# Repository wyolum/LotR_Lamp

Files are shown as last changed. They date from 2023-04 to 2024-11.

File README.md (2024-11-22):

# LotR_Lamp
3D printed Lord of the Rings inspired table / desk lamp.
Derived from jerome95's LotR Lamp on Instructables at https://www.instructables.com/Lord-of-the-Rings-Lamp/

I've completely redesigned this from the ground up in FreeCAD

## 3D Printed Parts
- BASE : Lamp base, which houses the micro-controller and a barrel socket adapter. Single color in black. Supports are optional (depending on how good the printer is). There are 4 holes for M3 screws. The 4 screws can act as feet, and if wired to the micro-controller, can be used as 4 touch pads to act as buttons. The buttons can then be used to cycle through different animations, or adjust LED intensity etc.
- BASE COVER : 2 color printing. The cover is black, and the embossed text and tree are white
- PILLAR LEFT and RIGHT : Vertical support pillars in two parts for easier printing and assembly. There is a channel for the wires from micro-controller to LED ring. There are a pair of 1.9 mm holes through which you can insert 1.75 mm filament to staple the top part of the two halves of the vertical pillars. The bottom of the pillars have screw fixing holes. Insert pillars through the Base Cover, and then insert the pillars in the Base. Finally, use 4 wood screws / self tapping screws to nicely hold it all together.
- RING COVER : This is the bottom part of the main ring, and is printed in GOLD / COPPER or similar filament.
- RING : This requires 2 color printing. The inner part of the shell and the text is in white / translucent, and the outer shell is in GOLD / COPPER.

## ELECTRONICS
- LED ring, with 64 addressable LEDs, WS2812 or similar.
- Micro-controller : I used Arduino Nano, but any controller will do the job.
- Example code is in the CODE sub folder

## RENDERS

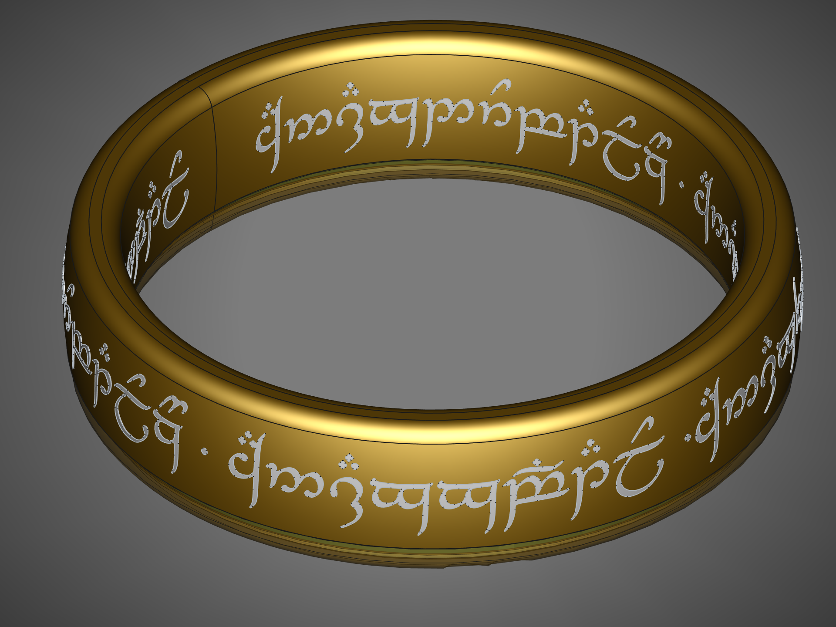
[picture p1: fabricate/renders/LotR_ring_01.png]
LotR Lamp


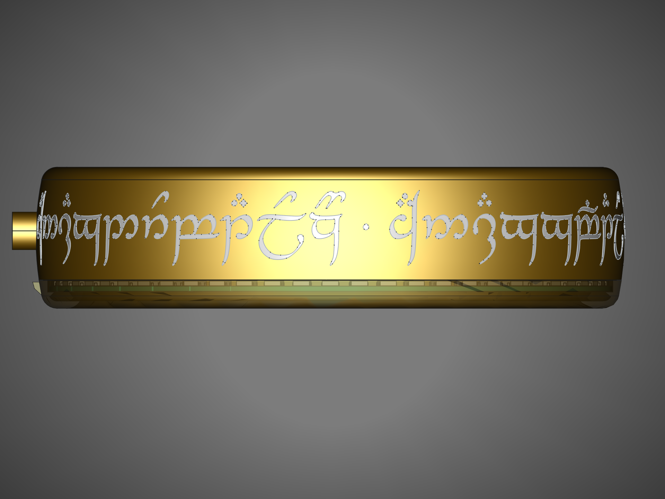
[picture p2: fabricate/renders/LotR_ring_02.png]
LotR Lamp


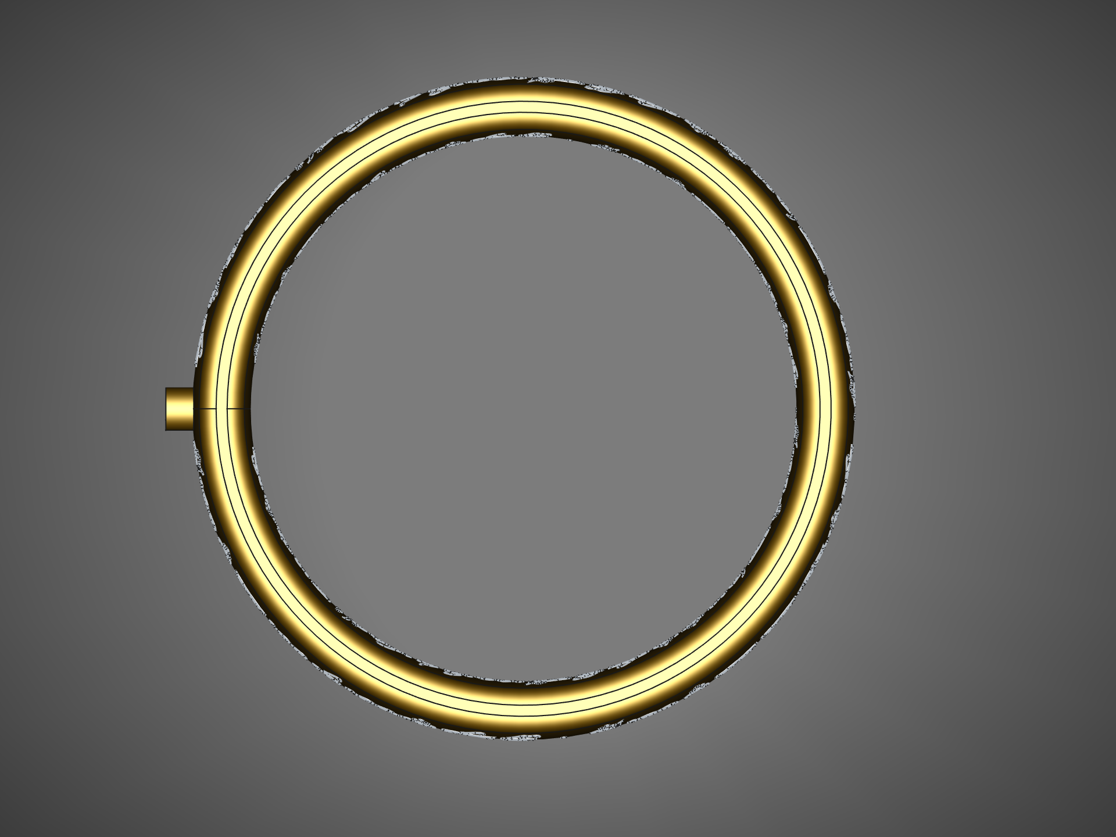
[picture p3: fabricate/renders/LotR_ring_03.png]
LotR Lamp


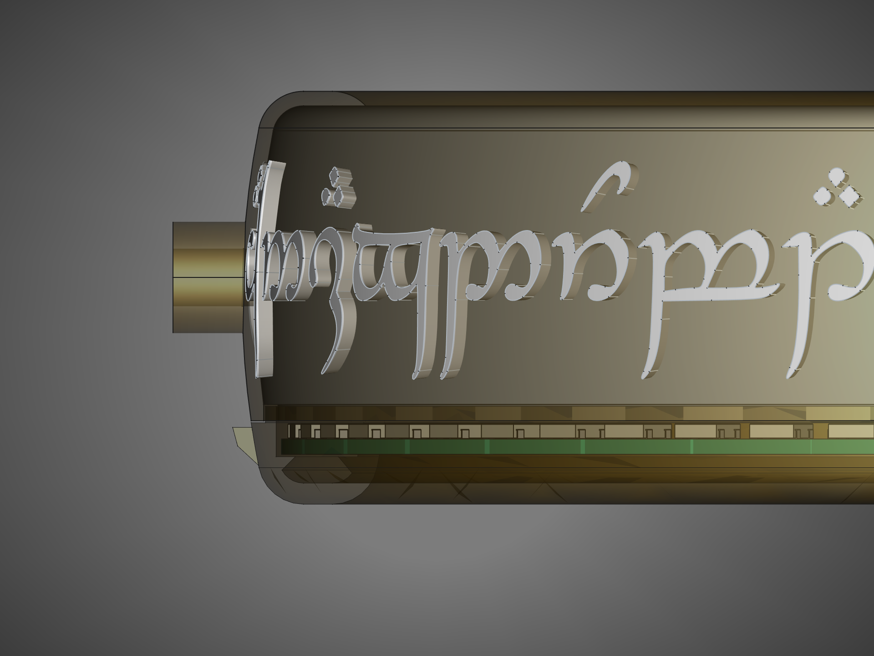
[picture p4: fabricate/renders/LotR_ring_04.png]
LotR Lamp


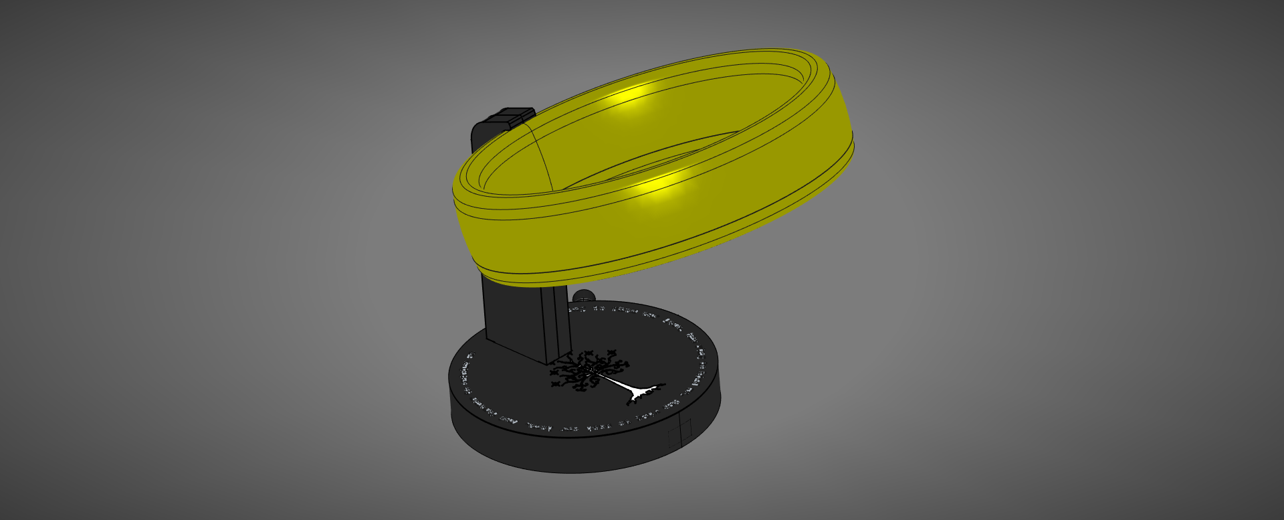
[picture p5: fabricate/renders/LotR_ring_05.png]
LotR Lamp


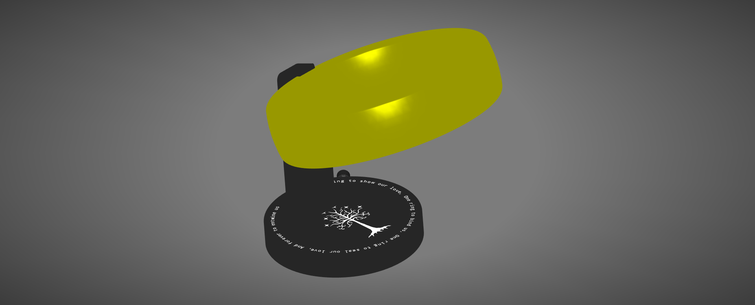
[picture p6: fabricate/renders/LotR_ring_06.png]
LotR Lamp


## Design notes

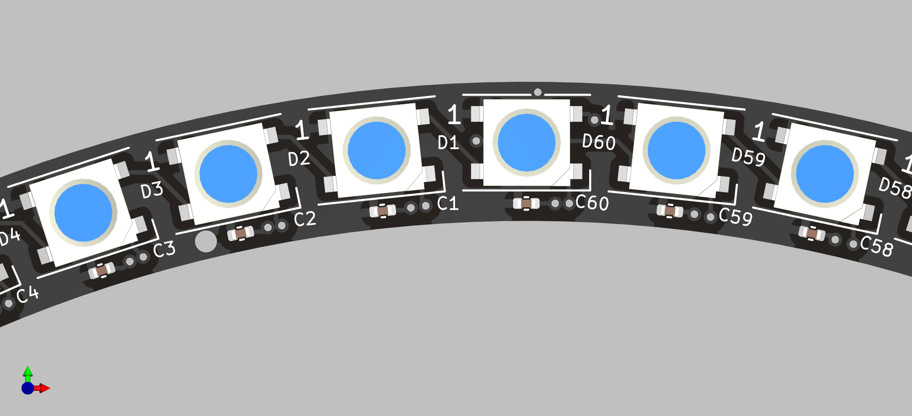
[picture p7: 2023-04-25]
LOTR_LED_RING_KiCAD/renders/LOTR_LED_RING_03.png

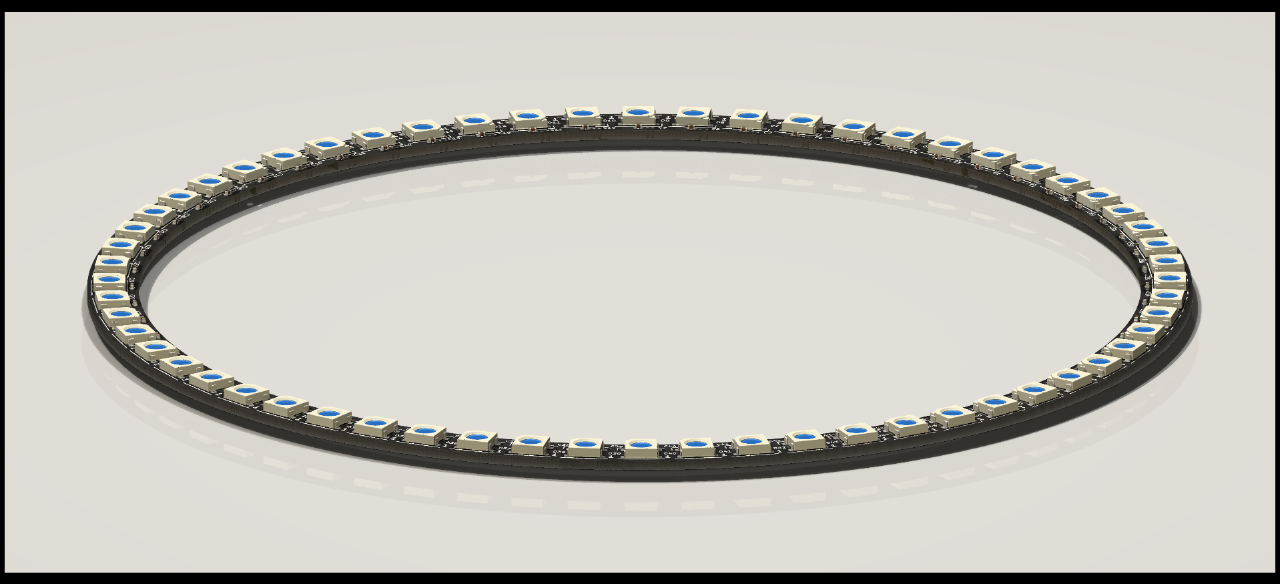
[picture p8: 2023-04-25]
LOTR_LED_RING_KiCAD/renders/LOTR_LED_RING_02.png

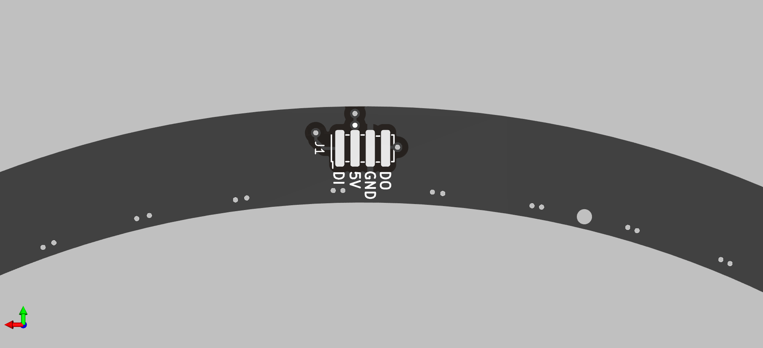
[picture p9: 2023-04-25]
LOTR_LED_RING_KiCAD/renders/LOTR_LED_RING_04.png

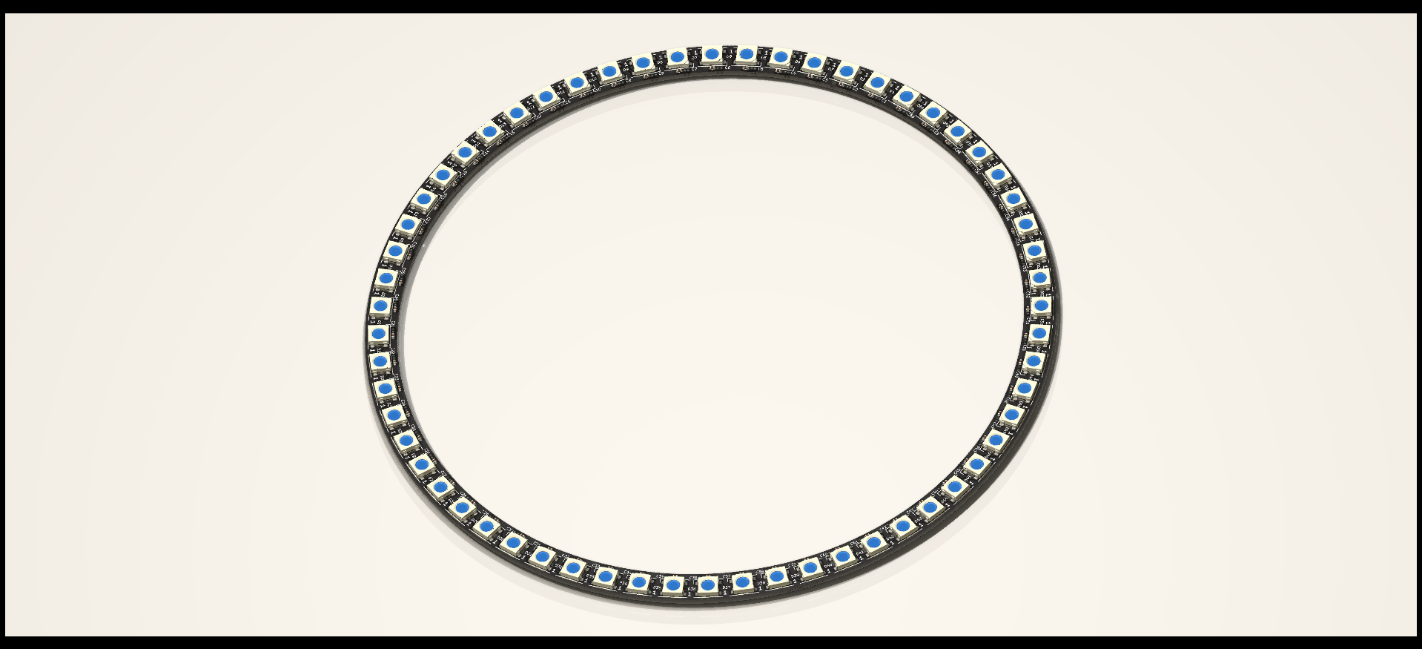
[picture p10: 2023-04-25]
LOTR_LED_RING_KiCAD/renders/LOTR_LED_RING_01.png

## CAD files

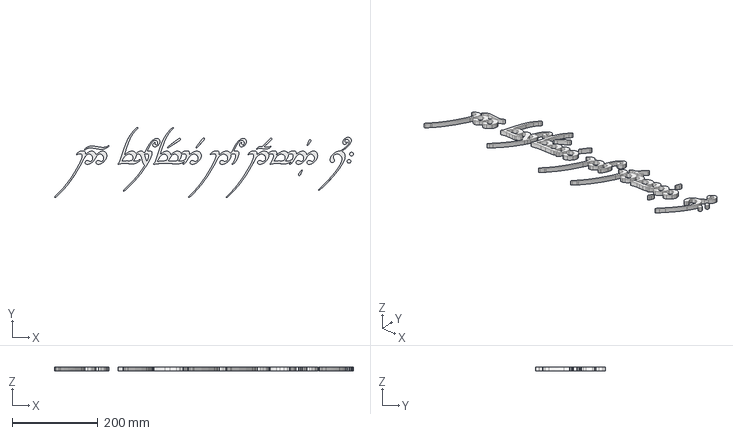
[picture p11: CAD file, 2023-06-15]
fabricate/data/H_N_elvish_line_4.FCStd
699.3 x 164.7 x 10.0 mm

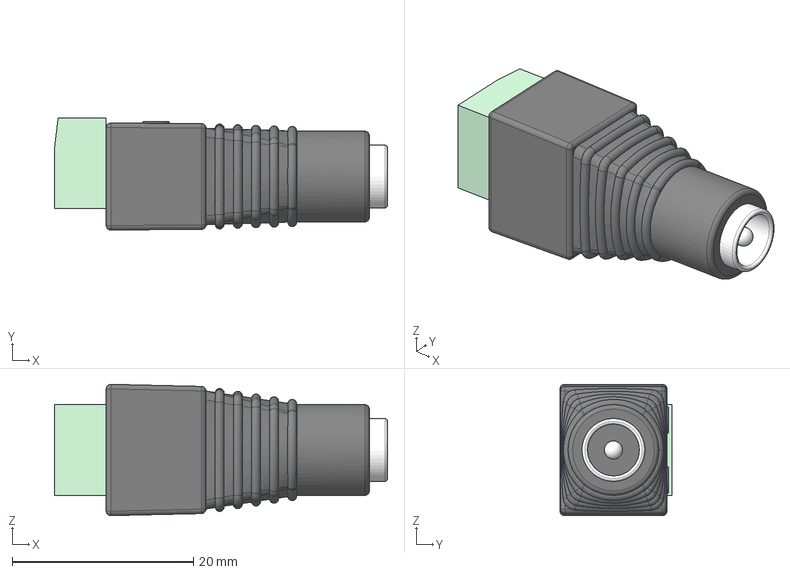
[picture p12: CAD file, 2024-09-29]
fabricate/dc-barrel-jack-adapter-female.step
36.7 x 12.3 x 14.5 mm
Adapter Housing
Housing
Terminal x 2
92000A013 x 2
Ground Jack
Power Jack

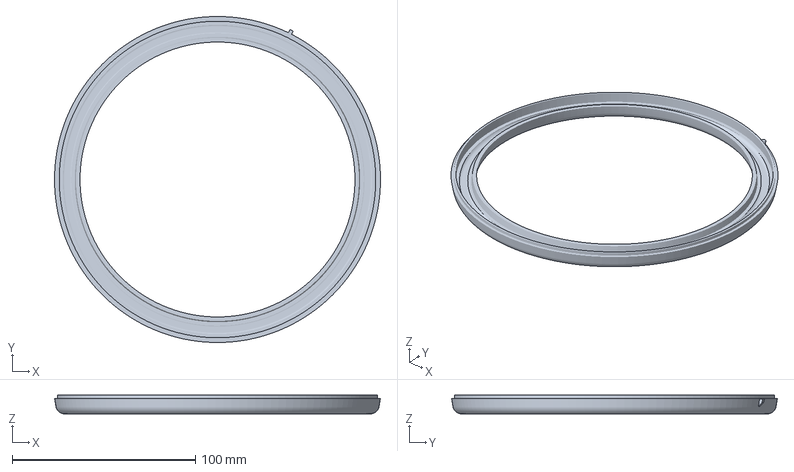
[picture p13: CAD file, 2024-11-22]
fabricate/gcode/LotR_ring_v5-ring_cover.3mf
177.7 x 177.7 x 10.2 mm

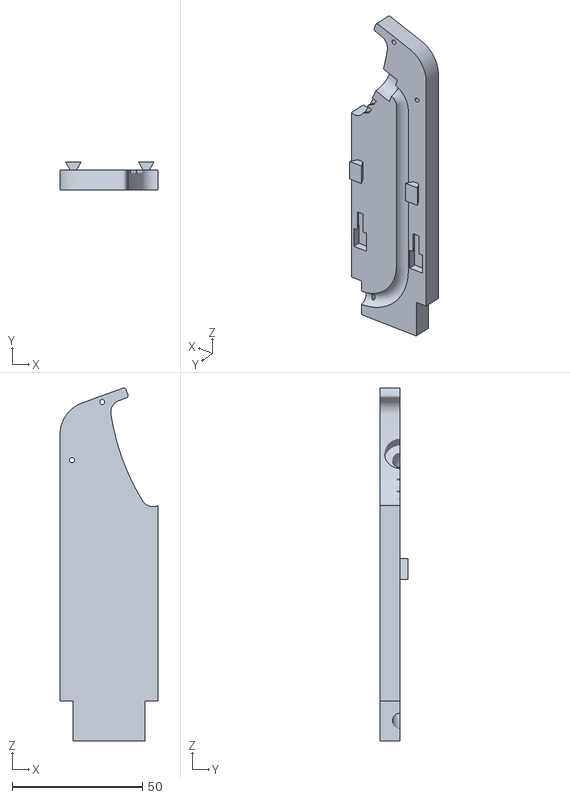
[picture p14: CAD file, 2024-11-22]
fabricate/STL/LotR_Base4-Pillar_Left.stl
37.6 x 10.8 x 135.6

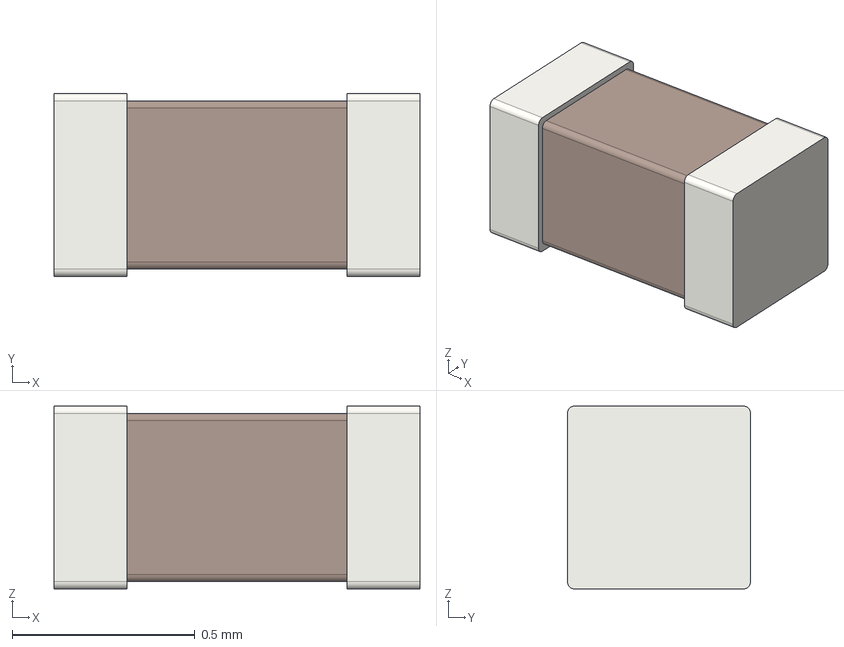
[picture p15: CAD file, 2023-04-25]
LOTR_LED_RING_KiCAD/3D_models/C_0402_1005Metric.step
1.00 x 0.5 x 0.5 mm

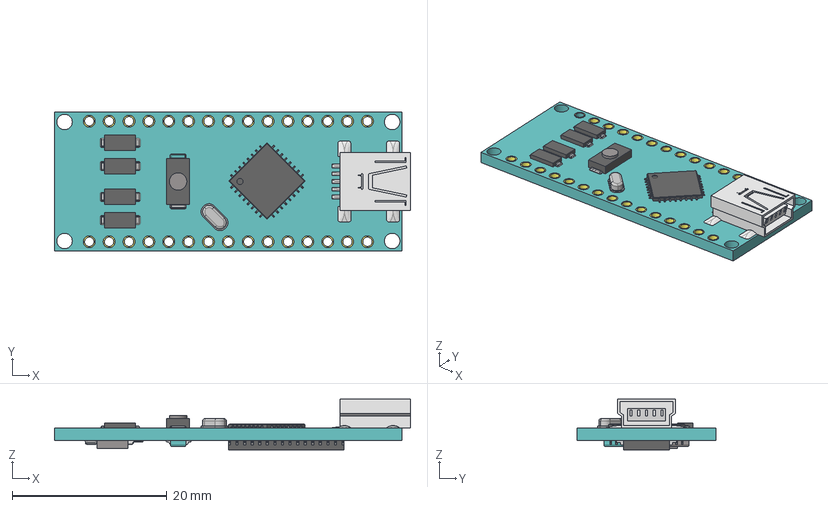
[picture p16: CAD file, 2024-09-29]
fabricate/arduino_nano.step
46.1 x 18.0 x 6.55 mm
USB
Component3(Mirror) x 16
Component5(Mirror) x 4
Component5(Mirror) (1) x 4

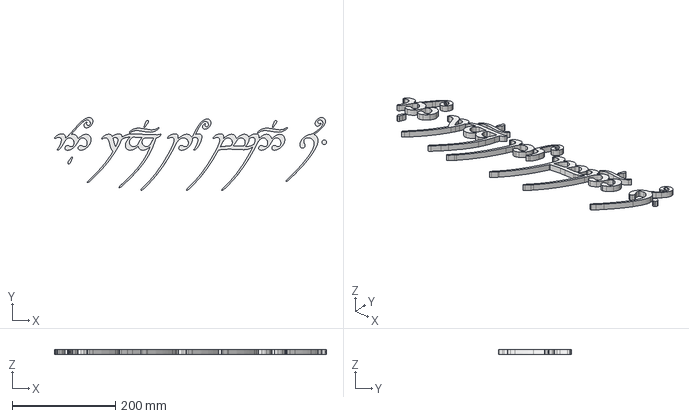
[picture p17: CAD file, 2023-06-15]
fabricate/data/H_N_elvish_line_2.FCStd
527.7 x 141.5 x 10.0 mm

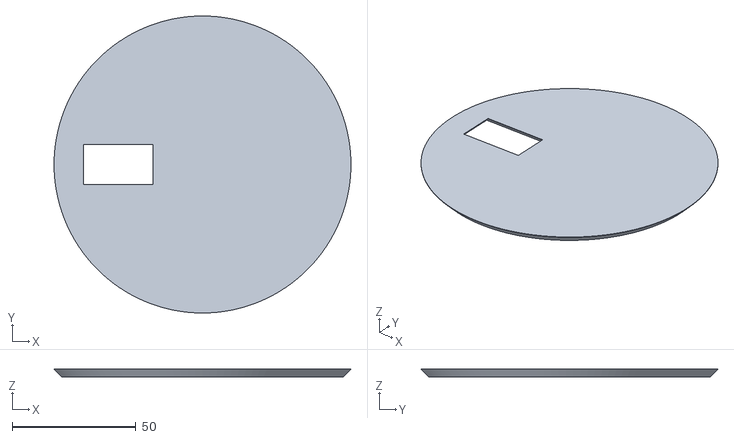
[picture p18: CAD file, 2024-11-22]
fabricate/STL/LotR_Base4-Base_Cover.stl
120.0 x 120.0 x 3.40

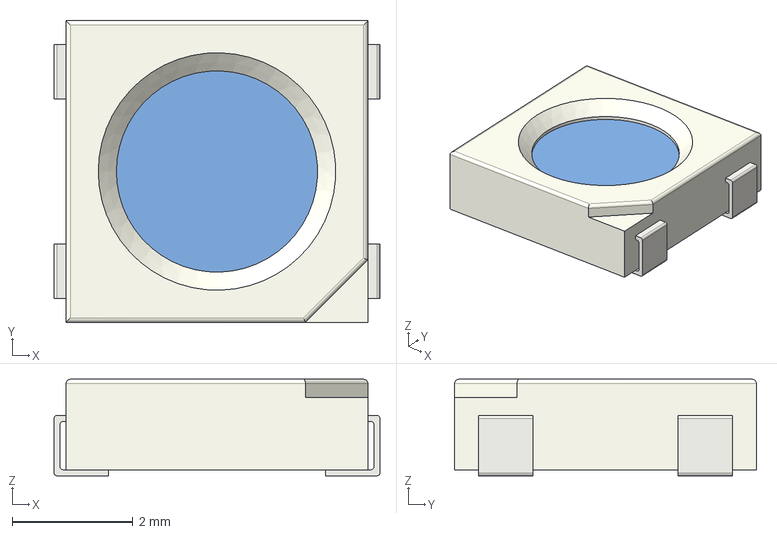
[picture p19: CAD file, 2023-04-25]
LOTR_LED_RING_KiCAD/3D_models/LED_WS2812B_PLCC4_5.0x5.0mm_P3.2mm.step
5.40 x 5.00 x 1.60 mm

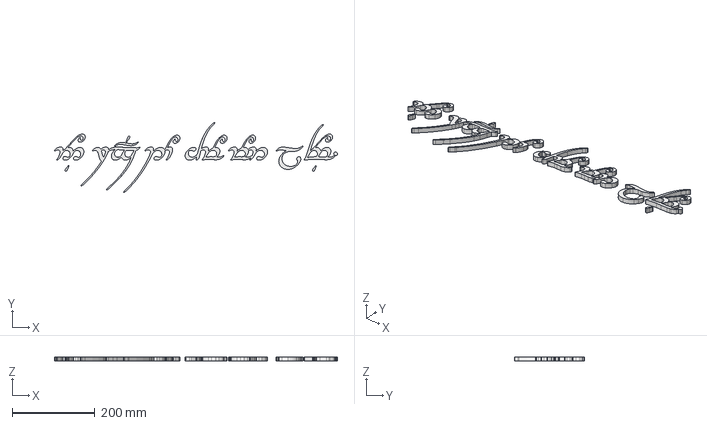
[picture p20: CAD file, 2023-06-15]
fabricate/data/H_N_elvish_line_1.FCStd
685.1 x 169.1 x 10.0 mm

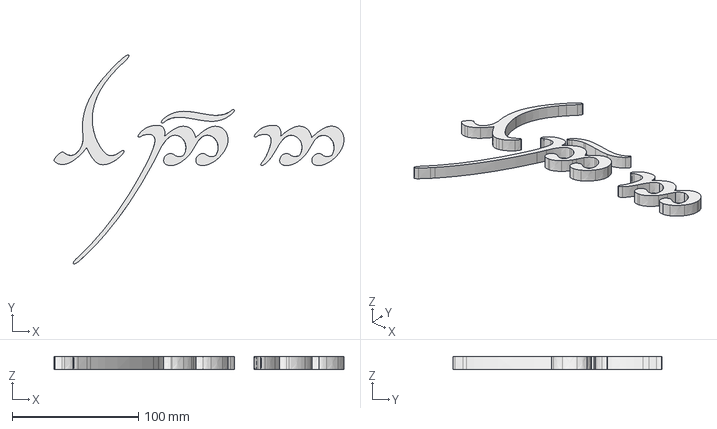
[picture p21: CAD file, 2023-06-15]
fabricate/data/H_N_elvish_line_5.FCStd
229.6 x 165.5 x 10.0 mm

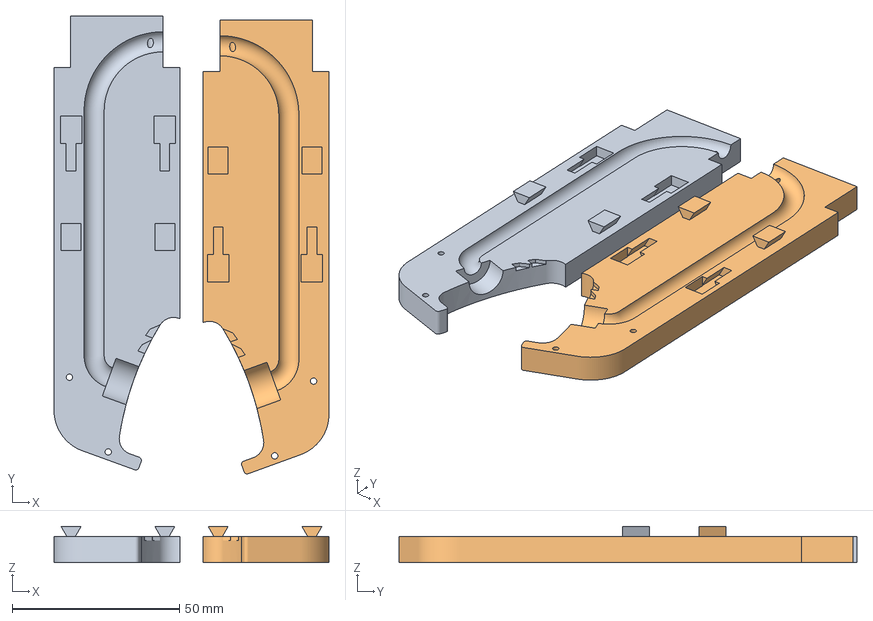
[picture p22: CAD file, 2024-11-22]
fabricate/gcode/LotR_Base4-Pillar_LR.3mf
82.1 x 136.7 x 10.8 mm
LotR_Base4-Pillar_Left.stl
LotR_Base4-Pillar_Right.stl

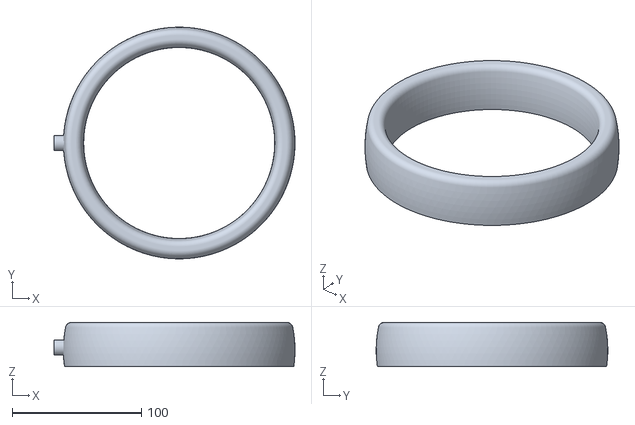
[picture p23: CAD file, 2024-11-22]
fabricate/STL/LotR_ring_v5-Body_outer_gold.stl
186.7 x 179.5 x 34.3

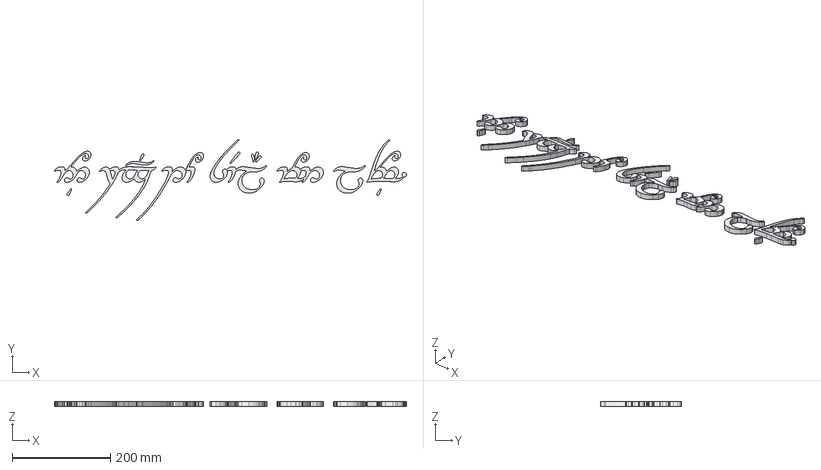
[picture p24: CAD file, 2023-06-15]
fabricate/data/H_N_elvish_line_3.FCStd
716.9 x 165.5 x 10.0 mm

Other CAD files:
fabricate/gcode/LotR_Base4-Pillar_LR.gcode.3mf
fabricate/gcode/LotR_Base4-Base.gcode.3mf
fabricate/STL/LotR_ring_v5-ring_cover.stl
fabricate/gcode/LotR_Base4-Base.3mf
fabricate/STL/LotR_Base4-Base.stl
fabricate/STL/LotR_Base4-Pillar_Right.stl
fabricate/STL/archive/LED_ring_v3_cover.stl
fabricate/STL/archive/LED_ring_v3_gold.stl
fabricate/STL/archive/LotR_Base2-Base.stl
fabricate/STL/archive/LotR_Base2-Body (mirrored).stl
fabricate/STL/archive/LotR_Base2-Body.stl
fabricate/STL/archive/LotR_Base2-Cut001.stl
fabricate/STL/archive/LotR_Base2_bottom.stl
fabricate/STL/archive/LotR_Base2_cover-Top_Cover.stl
fabricate/archive/Barad_dur_base.STL
fabricate/archive/Cover_base.STL
fabricate/archive/LED_ring_amzn_2.FCStd
fabricate/archive/LED_ring_amzn_3.FCStd
fabricate/archive/LED_ring_amzn_6.FCStd
fabricate/archive/LED_ring_amzn_7-ring_cover.step
fabricate/archive/LED_ring_amzn_7-ring_cover.stl
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

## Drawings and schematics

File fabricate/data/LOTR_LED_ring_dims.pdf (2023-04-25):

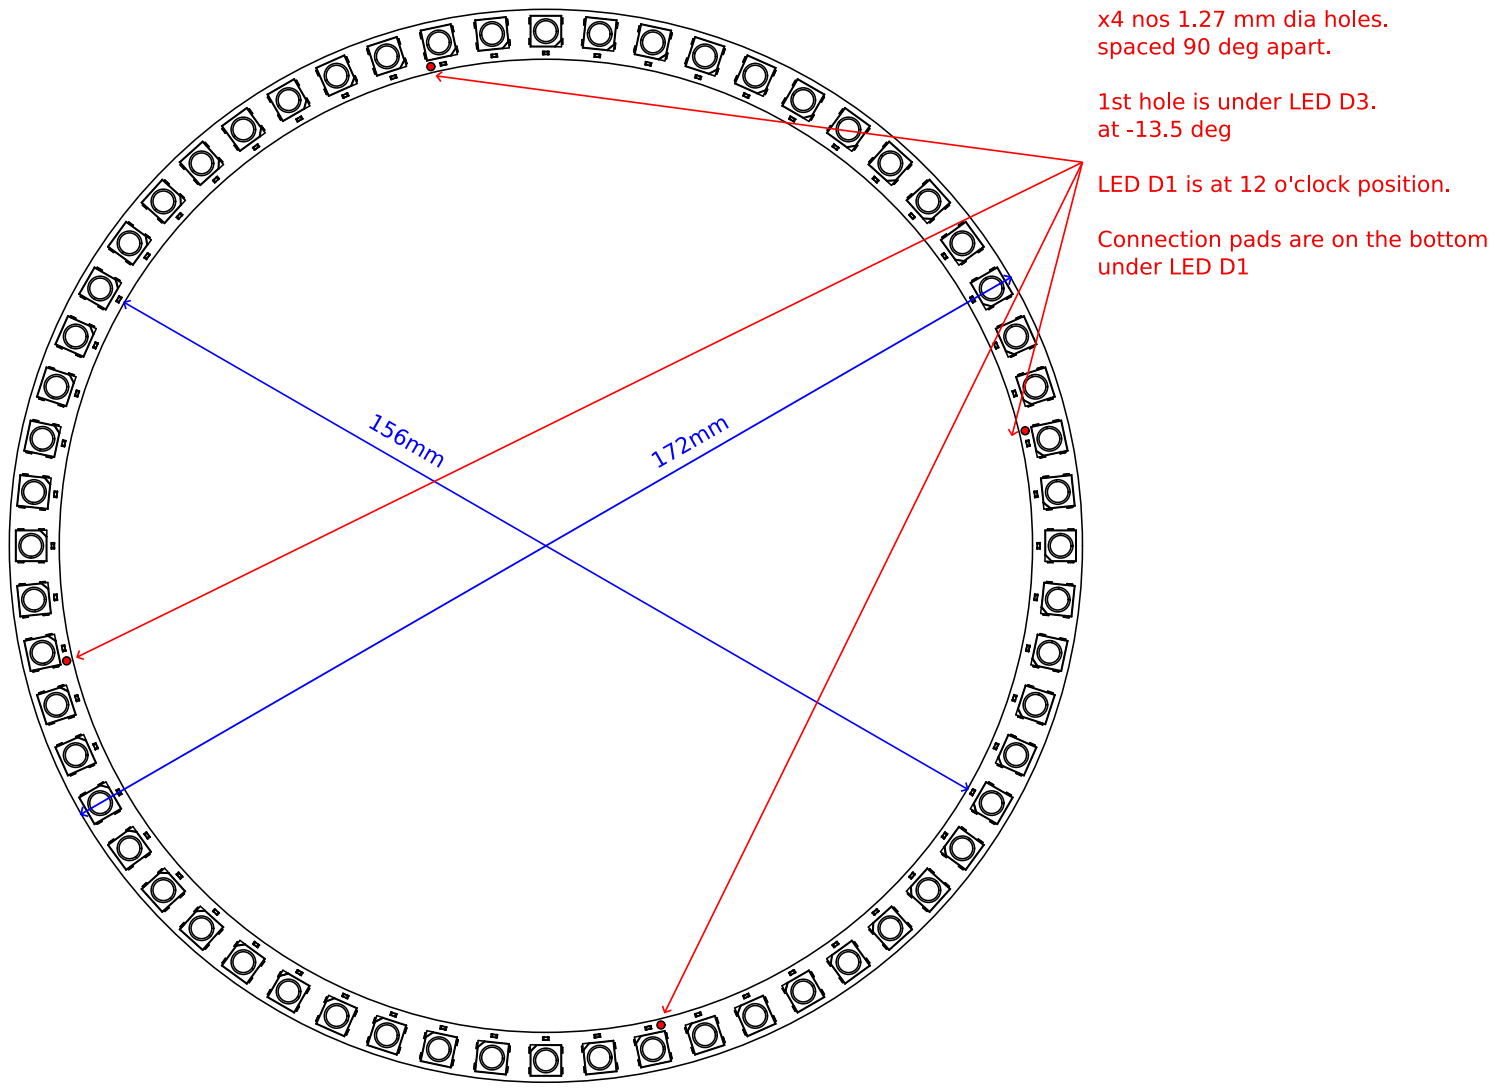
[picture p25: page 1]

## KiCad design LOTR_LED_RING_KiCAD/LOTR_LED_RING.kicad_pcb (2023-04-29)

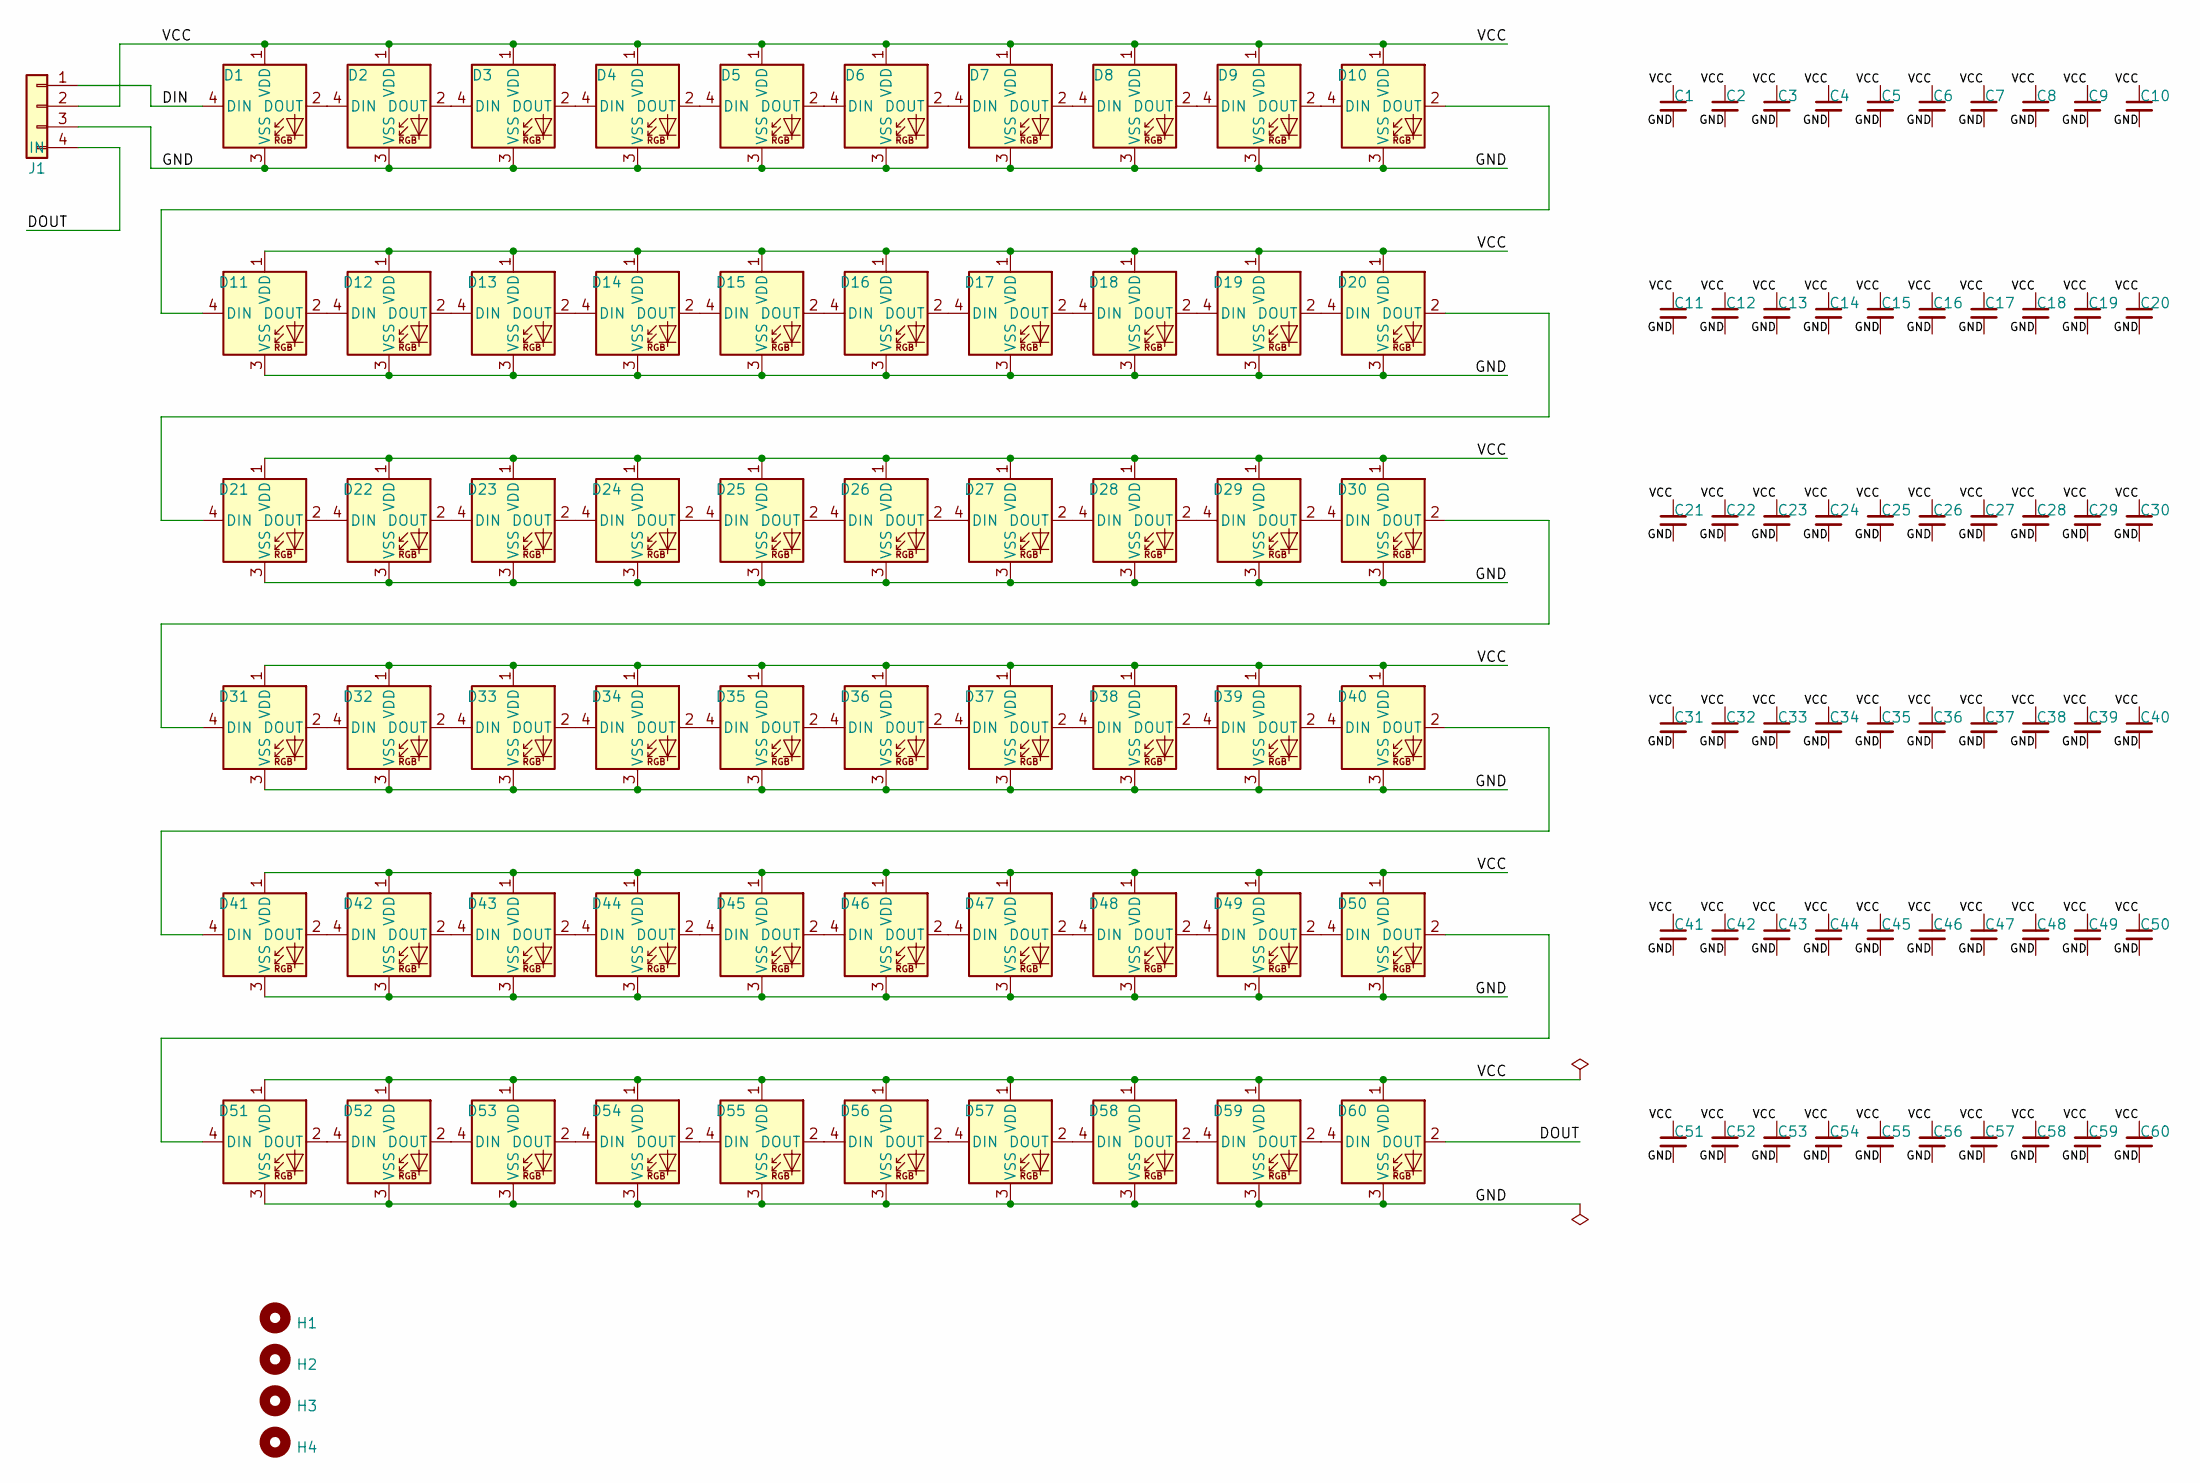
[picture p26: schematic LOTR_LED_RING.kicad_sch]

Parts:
C1, C2, C3, C4, C5, C6, C7, C8, C9, C10, C11, C12, C13, C14, C15, C16, C17, C18, C19, C20, C21, C22, C23, C24, C25, C26, C27, C28, C29, C30, C31, C32, C33, C34, C35, C36, C37, C38, C39, C40, C41, C42, C43, C44, C45, C46, C47, C48, C49, C50, C51, C52, C53, C54, C55, C56, C57, C58, C59, C60: 100nF; C_0402_1005Metric
D1, D2, D3, D4, D5, D6, D7, D8, D9, D10, D11, D12, D13, D14, D15, D16, D17, D18, D19, D20, D21, D22, D23, D24, D25, D26, D27, D28, D29, D30, D31, D32, D33, D34, D35, D36, D37, D38, D39, D40, D41, D42, D43, D44, D45, D46, D47, D48, D49, D50, D51, D52, D53, D54, D55, D56, D57, D58, D59, D60: WS2812B; LED_WS2812B_PLCC4_5.0x5.0mm_P3.2mm
H1, H2, H3, H4: MountingHole; MountingHole_1.27mm
J1: IN; PinHeader_1x04_P1.27mm_Vertical_SMD_Pin1Left

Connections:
/DIN: D1.4 (DIN), J1.1
/DOUT: D60.2 (DOUT), J1.4
/GND: C1.2, C2.2, C3.2, C4.2, C5.2, C6.2, C7.2, C8.2, C9.2, C10.2, C11.2, C12.2, C13.2, C14.2, C15.2, C16.2, C17.2, C18.2, C19.2, C20.2, C21.2, C22.2, C23.2, C24.2, C25.2, C26.2, C27.2, C28.2, C29.2, C30.2, C31.2, C32.2, C33.2, C34.2, C35.2, C36.2, C37.2, C38.2, C39.2, C40.2, C41.2, C42.2, C43.2, C44.2, C45.2, C46.2, C47.2, C48.2, C49.2, C50.2, C51.2, C52.2, C53.2, C54.2, C55.2, C56.2, C57.2, C58.2, C59.2, C60.2, D1.3 (VSS), D2.3 (VSS), D3.3 (VSS), D4.3 (VSS), D5.3 (VSS), D6.3 (VSS), D7.3 (VSS), D8.3 (VSS), D9.3 (VSS), D10.3 (VSS), D11.3 (VSS), D12.3 (VSS), D13.3 (VSS), D14.3 (VSS), D15.3 (VSS), D16.3 (VSS), D17.3 (VSS), D18.3 (VSS), D19.3 (VSS), D20.3 (VSS), D21.3 (VSS), D22.3 (VSS), D23.3 (VSS), D24.3 (VSS), D25.3 (VSS), D26.3 (VSS), D27.3 (VSS), D28.3 (VSS), D29.3 (VSS), D30.3 (VSS), D31.3 (VSS), D32.3 (VSS), D33.3 (VSS), D34.3 (VSS), D35.3 (VSS), D36.3 (VSS), D37.3 (VSS), D38.3 (VSS), D39.3 (VSS), D40.3 (VSS), D41.3 (VSS), D42.3 (VSS), D43.3 (VSS), D44.3 (VSS), D45.3 (VSS), D46.3 (VSS), D47.3 (VSS), D48.3 (VSS), D49.3 (VSS), D50.3 (VSS), D51.3 (VSS), D52.3 (VSS), D53.3 (VSS), D54.3 (VSS), D55.3 (VSS), D56.3 (VSS), D57.3 (VSS), D58.3 (VSS), D59.3 (VSS), D60.3 (VSS), J1.3
/VCC: C1.1, C2.1, C3.1, C4.1, C5.1, C6.1, C7.1, C8.1, C9.1, C10.1, C11.1, C12.1, C13.1, C14.1, C15.1, C16.1, C17.1, C18.1, C19.1, C20.1, C21.1, C22.1, C23.1, C24.1, C25.1, C26.1, C27.1, C28.1, C29.1, C30.1, C31.1, C32.1, C33.1, C34.1, C35.1, C36.1, C37.1, C38.1, C39.1, C40.1, C41.1, C42.1, C43.1, C44.1, C45.1, C46.1, C47.1, C48.1, C49.1, C50.1, C51.1, C52.1, C53.1, C54.1, C55.1, C56.1, C57.1, C58.1, C59.1, C60.1, D1.1 (VDD), D2.1 (VDD), D3.1 (VDD), D4.1 (VDD), D5.1 (VDD), D6.1 (VDD), D7.1 (VDD), D8.1 (VDD), D9.1 (VDD), D10.1 (VDD), D11.1 (VDD), D12.1 (VDD), D13.1 (VDD), D14.1 (VDD), D15.1 (VDD), D16.1 (VDD), D17.1 (VDD), D18.1 (VDD), D19.1 (VDD), D20.1 (VDD), D21.1 (VDD), D22.1 (VDD), D23.1 (VDD), D24.1 (VDD), D25.1 (VDD), D26.1 (VDD), D27.1 (VDD), D28.1 (VDD), D29.1 (VDD), D30.1 (VDD), D31.1 (VDD), D32.1 (VDD), D33.1 (VDD), D34.1 (VDD), D35.1 (VDD), D36.1 (VDD), D37.1 (VDD), D38.1 (VDD), D39.1 (VDD), D40.1 (VDD), D41.1 (VDD), D42.1 (VDD), D43.1 (VDD), D44.1 (VDD), D45.1 (VDD), D46.1 (VDD), D47.1 (VDD), D48.1 (VDD), D49.1 (VDD), D50.1 (VDD), D51.1 (VDD), D52.1 (VDD), D53.1 (VDD), D54.1 (VDD), D55.1 (VDD), D56.1 (VDD), D57.1 (VDD), D58.1 (VDD), D59.1 (VDD), D60.1 (VDD), J1.2
unnamed: D1.2 (DOUT), D2.4 (DIN)
unnamed: D2.2 (DOUT), D3.4 (DIN)
unnamed: D3.2 (DOUT), D4.4 (DIN)
unnamed: D4.2 (DOUT), D5.4 (DIN)
unnamed: D5.2 (DOUT), D6.4 (DIN)
unnamed: D6.2 (DOUT), D7.4 (DIN)
unnamed: D7.2 (DOUT), D8.4 (DIN)
unnamed: D8.2 (DOUT), D9.4 (DIN)
unnamed: D9.2 (DOUT), D10.4 (DIN)
unnamed: D10.2 (DOUT), D11.4 (DIN)
unnamed: D11.2 (DOUT), D12.4 (DIN)
unnamed: D12.2 (DOUT), D13.4 (DIN)
unnamed: D13.2 (DOUT), D14.4 (DIN)
unnamed: D14.2 (DOUT), D15.4 (DIN)
unnamed: D15.2 (DOUT), D16.4 (DIN)
unnamed: D16.2 (DOUT), D17.4 (DIN)
unnamed: D17.2 (DOUT), D18.4 (DIN)
unnamed: D18.2 (DOUT), D19.4 (DIN)
unnamed: D19.2 (DOUT), D20.4 (DIN)
unnamed: D20.2 (DOUT), D21.4 (DIN)
unnamed: D21.2 (DOUT), D22.4 (DIN)
unnamed: D22.2 (DOUT), D23.4 (DIN)
unnamed: D23.2 (DOUT), D24.4 (DIN)
unnamed: D24.2 (DOUT), D25.4 (DIN)
unnamed: D25.2 (DOUT), D26.4 (DIN)
unnamed: D26.2 (DOUT), D27.4 (DIN)
unnamed: D27.2 (DOUT), D28.4 (DIN)
unnamed: D28.2 (DOUT), D29.4 (DIN)
unnamed: D29.2 (DOUT), D30.4 (DIN)
unnamed: D30.2 (DOUT), D31.4 (DIN)
unnamed: D31.2 (DOUT), D32.4 (DIN)
unnamed: D32.2 (DOUT), D33.4 (DIN)
unnamed: D33.2 (DOUT), D34.4 (DIN)
unnamed: D34.2 (DOUT), D35.4 (DIN)
unnamed: D35.2 (DOUT), D36.4 (DIN)
unnamed: D36.2 (DOUT), D37.4 (DIN)
unnamed: D37.2 (DOUT), D38.4 (DIN)
unnamed: D38.2 (DOUT), D39.4 (DIN)
unnamed: D39.2 (DOUT), D40.4 (DIN)
unnamed: D40.2 (DOUT), D41.4 (DIN)
unnamed: D41.2 (DOUT), D42.4 (DIN)
unnamed: D42.2 (DOUT), D43.4 (DIN)
unnamed: D43.2 (DOUT), D44.4 (DIN)
unnamed: D44.2 (DOUT), D45.4 (DIN)
unnamed: D45.2 (DOUT), D46.4 (DIN)
unnamed: D46.2 (DOUT), D47.4 (DIN)
unnamed: D47.2 (DOUT), D48.4 (DIN)
unnamed: D48.2 (DOUT), D49.4 (DIN)
unnamed: D49.2 (DOUT), D50.4 (DIN)
unnamed: D50.2 (DOUT), D51.4 (DIN)
unnamed: D51.2 (DOUT), D52.4 (DIN)
unnamed: D52.2 (DOUT), D53.4 (DIN)
unnamed: D53.2 (DOUT), D54.4 (DIN)
unnamed: D54.2 (DOUT), D55.4 (DIN)
unnamed: D55.2 (DOUT), D56.4 (DIN)
unnamed: D56.2 (DOUT), D57.4 (DIN)
unnamed: D57.2 (DOUT), D58.4 (DIN)
unnamed: D58.2 (DOUT), D59.4 (DIN)
unnamed: D59.2 (DOUT), D60.4 (DIN)

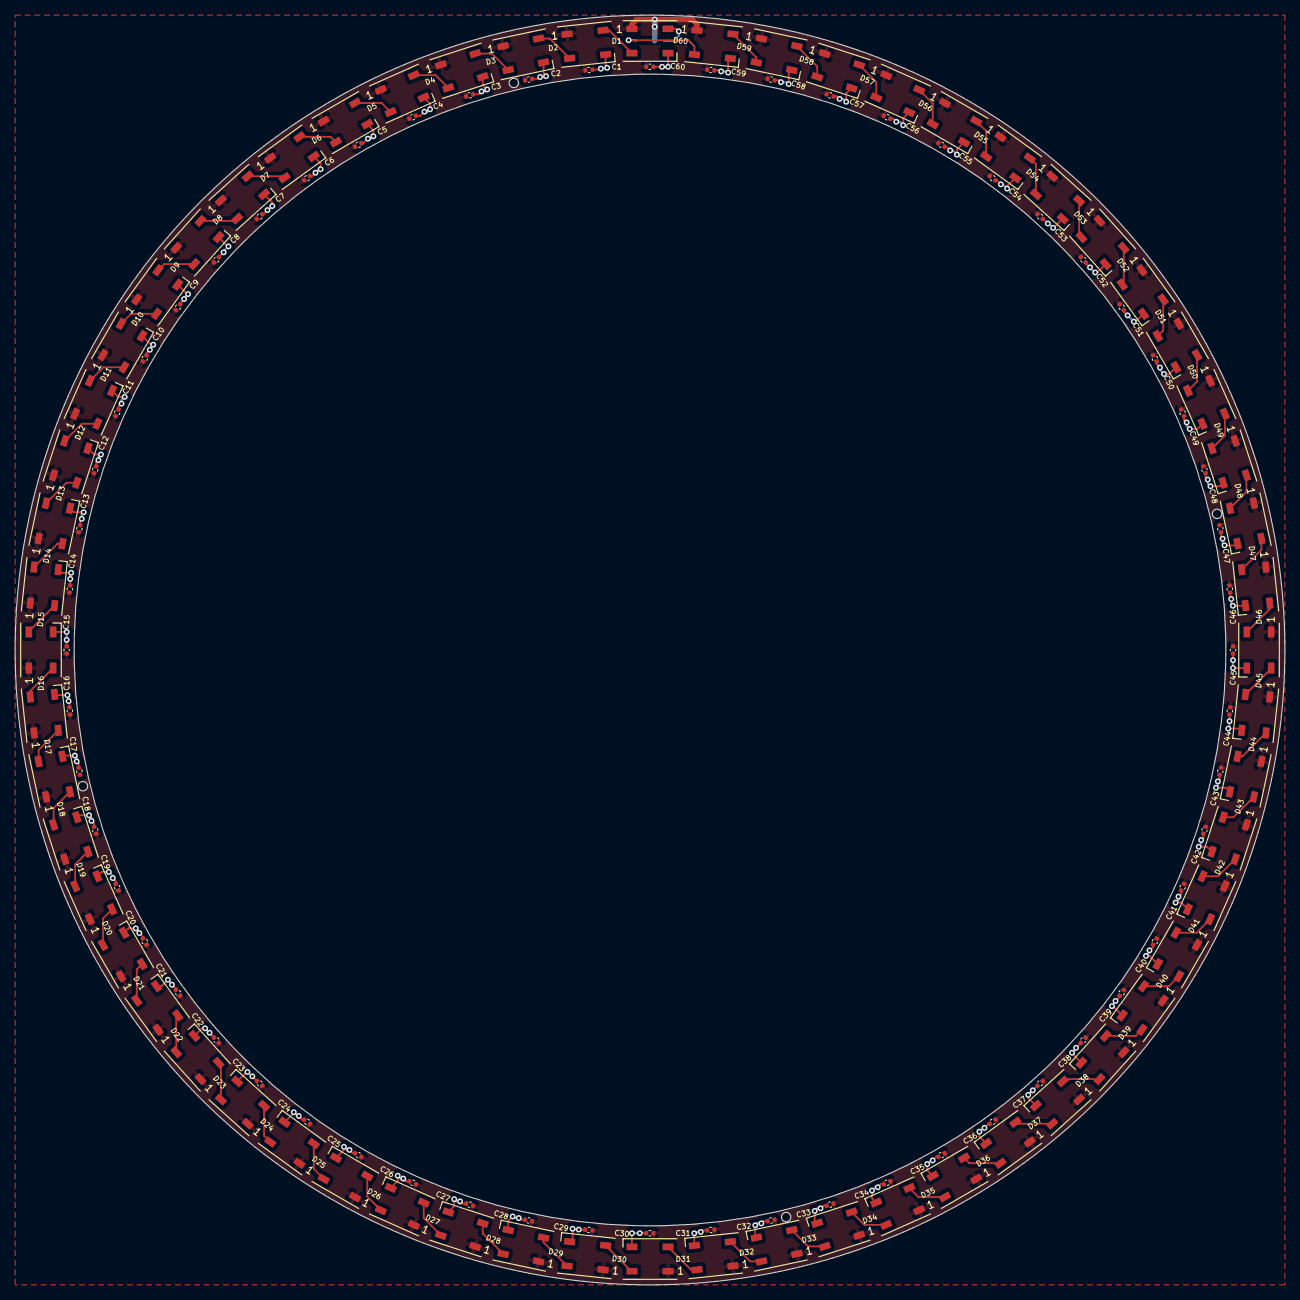
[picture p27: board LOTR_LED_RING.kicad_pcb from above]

Board: 2 copper layers, 172.0 x 172.0 mm, 121 parts (1 on the bottom side), 63 nets.

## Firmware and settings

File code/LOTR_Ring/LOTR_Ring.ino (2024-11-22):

#include <Adafruit_NeoPixel.h>

#include <ADCTouch.h>
int ref0, ref1;     //reference values to remove offset

#ifdef __AVR__
  #include <avr/power.h>
#endif

#define PIN 3

// Parameter 1 = number of pixels in strip
// Parameter 2 = Arduino pin number (most are valid)
// Parameter 3 = pixel type flags, add together as needed:
//   NEO_KHZ800  800 KHz bitstream (most NeoPixel products w/WS2812 LEDs)
//   NEO_KHZ400  400 KHz (classic 'v1' (not v2) FLORA pixels, WS2811 drivers)
//   NEO_GRB     Pixels are wired for GRB bitstream (most NeoPixel products)
//   NEO_RGB     Pixels are wired for RGB bitstream (v1 FLORA pixels, not v2)
//   NEO_RGBW    Pixels are wired for RGBW bitstream (NeoPixel RGBW products)
Adafruit_NeoPixel strip(64, PIN, NEO_GRB + NEO_KHZ800);

// IMPORTANT: To reduce NeoPixel burnout risk, add 1000 uF capacitor across
// pixel power leads, add 300 - 500 Ohm resistor on first pixel's data input
// and minimize distance between Arduino and first pixel.  Avoid connecting
// on a live circuit...if you must, connect GND first.

void setup() {
  // This is for Trinket 5V 16MHz, you can remove these three lines if you are not using a Trinket
  #if defined (__AVR_ATtiny85__)
    if (F_CPU == 16000000) clock_prescale_set(clock_div_1);
  #endif
  // End of trinket special code
  Serial.begin(9600); // open the serial port at 9600 bps
  strip.begin();
  strip.setBrightness(255);
  strip.show(); // Initialize all pixels to 'off'

  // No pins to setup, pins can still be used regularly, although it will affect readings

    ref0 = ADCTouch.read(A0, 500);    //create reference values to 
    ref1 = ADCTouch.read(A1, 500);    //account for the capacitance of the pad
  
}

void loop() {
uint16_t i, j, k;
uint16_t f=255;

    int value0 = ADCTouch.read(A0);   //no second parameter
    int value1 = ADCTouch.r
    
    
    ead(A1);   //   --> 100 samples

    value0 -= ref0;       //remove offset
    value1 -= ref1;

    Serial.print(value0 > 40);    //send (boolean) pressed or not pressed
    Serial.print("\t");           //use if(value > threshold) to get the state of a button

    Serial.print(value1 > 40);
    Serial.print("\t\t");

    Serial.print(value0);             //send actual reading
    Serial.print("\t");
  
    Serial.println(value1);
    delay(100);

    five_led_snake();
    five_led_snake();
    
      for(i=0; i< strip.numPixels(); i++) {
      strip.setPixelColor(i,255,165,0); //original color is 255,85,0)
      strip.show();
      delay(30);
      }

      for(i=0; i< strip.numPixels(); i++) {
      strip.setPixelColor(i,0,0,0);
      strip.show();
      delay(30);
      }

      for(i=0; i< strip.numPixels(); i++) {
      strip.setPixelColor(i,255,165,0);
      strip.show();
      delay(30);
      }
      
      for(i=0; i< strip.numPixels(); i++) {
      strip.setPixelColor(i,0,0,0);
      strip.show();
      delay(30);
      }

      for(i=0; i< strip.numPixels(); i++) {
      strip.setPixelColor(i,255,165,0);
      strip.show();
      delay(30);
      }
      
      delay(10000);


strip.clear();
    
  
}


void five_led_snake(){

    for(int i=0; i< strip.numPixels(); i++) {
      strip.setPixelColor(0+i,255,165,0); // original color is 255,80 or 85,0
      strip.setPixelColor(1+i,255,165,0);
      strip.setPixelColor(2+i,255,165,0);
      strip.setPixelColor(3+i,255,165,0);
      strip.setPixelColor(4+i,255,165,0);
      strip.show();
      delay(50);
      strip.setPixelColor(0+i,0,0,0);
      strip.setPixelColor(1+i,0,0,0);
      strip.setPixelColor(2+i,0,0,0);
      strip.setPixelColor(3+i,0,0,0);
      strip.setPixelColor(4+i,0,0,0);
      strip.show();
      if (i>55) {
      strip.setPixelColor(0,255,165,0);
      }
      if (i>56) {
      strip.setPixelColor(1,255,165,0);
      }
      if (i>57) {
      strip.setPixelColor(2,255,165,0);
      }
      if (i>58) {
      strip.setPixelColor(3,255,165,0);
      }
      if (i>59) {
      strip.setPixelColor(4,255,165,0);
      }
    }
  
}

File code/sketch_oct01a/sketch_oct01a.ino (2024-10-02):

#include <FastLED.h>
#include <CapacitiveSensor.h>

#define PIN_LED 6
#define PIN_TOUCH1 2
#define PIN_TOUCH2 3
#define PIN_TOUCH3 4
#define PIN_TOUCH4 5

#define DATA_PIN    3
//#define CLK_PIN   4
#define LED_TYPE    WS2811
#define COLOR_ORDER GRB
#define NUM_LEDS    64
CRGB leds[NUM_LEDS];

#define BRIGHTNESS          96
#define FRAMES_PER_SECOND  120

// FastLED.h leds(NUM_LEDS, PIN_LED);

// Capacitive sensor pins
CapacitiveSensor sensor1 = CapacitiveSensor(PIN_TOUCH1, PIN_TOUCH1);
CapacitiveSensor sensor2 = CapacitiveSensor(PIN_TOUCH2, PIN_TOUCH2);
CapacitiveSensor sensor3 = CapacitiveSensor(PIN_TOUCH3, PIN_TOUCH3);
CapacitiveSensor sensor4 = CapacitiveSensor(PIN_TOUCH4, PIN_TOUCH4);

// Global variables for brightness, speed, color, and original values
int brightness = 128;
int speed = 50;
int color = 0; // 0 for red, 1 for green, 2 for blue
int originalBrightness = 128;
int originalSpeed = 50;
int originalColor = 0;

void setup() {
  FastLED.setBrightness(brightness);
  originalBrightness = brightness;
  originalSpeed = speed;
  originalColor = color;
}

void loop() {
  // Read capacitive sensor values
  long sensorValue1 = sensor1.capacitance();
  long sensorValue2 = sensor2.capacitance();
  long sensorValue3 = sensor3.capacitance();
  long sensorValue4 = sensor4.capacitance();

  // Check for touch events
  if (sensorValue1 > 1000) { // Adjust threshold as needed
    brightness = (brightness + 16) % 256;
    FastLED.setBrightness(brightness);
  }
  if (sensorValue2 > 1000) {
    speed = (speed + 10) % 256;
  }
  if (sensorValue3 > 1000) {
    color = (color + 1) % 3;
  }
  if (sensorValue4 > 1000) {
    brightness = originalBrightness;
    speed = originalSpeed;
    color = originalColor;
    FastLED.setBrightness(brightness);
  }

  // Update LED strip based on current values
  for (int i = 0; i < NUM_LEDS; i++) {
    switch (color) {
      case 0:
        leds[i] = CRGB::Red;
        break;
      case 1:
        leds[i] = CRGB::Green;
        break;
      case 2:
        leds[i] = CRGB::Blue;
        break;
    }
  }
  FastLED.show();
  delay(speed);
}

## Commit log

2023-04-29 added several versions in fabricate folder
    [LED_ring_amzn_2.FCStd, LED_ring_amzn_3.FCStd, LOTR_LED_RING.kicad_pcb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]
2023-06-15 rebuilt lost files
    [Barad_dur_base.STL, Cover_base (1).STL, Cover_base.STL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]
2023-06-16 modified Ring attachment cylinder
    [LED_ring_amzn_7_ring.step, LED_ring_amzn_7_ring.stl]
2023-06-16 added cover for LED ring STL
    [LED_ring_amzn_7-ring_cover.step, LED_ring_amzn_7-ring_cover.stl]
2024-09-29 new base for LoTR ring lamp
    [Barad_dur_base.STL, Cover_base.STL, LotR_Base.FCStd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]
2024-10-02 minor mods to new base
    [LotR_Base2-Base.stl]
2024-11-22 almost final version
    [Barad_dur_base.STL, C_0402_1005Metric.step, Cover_base.STL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]

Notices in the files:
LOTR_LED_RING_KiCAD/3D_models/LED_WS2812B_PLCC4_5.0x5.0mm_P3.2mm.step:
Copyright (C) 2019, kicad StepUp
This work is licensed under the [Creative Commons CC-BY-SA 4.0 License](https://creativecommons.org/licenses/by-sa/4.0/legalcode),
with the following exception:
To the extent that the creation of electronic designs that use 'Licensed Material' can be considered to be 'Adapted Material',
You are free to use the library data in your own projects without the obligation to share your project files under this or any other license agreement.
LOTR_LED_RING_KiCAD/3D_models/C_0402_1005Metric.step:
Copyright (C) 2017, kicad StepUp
